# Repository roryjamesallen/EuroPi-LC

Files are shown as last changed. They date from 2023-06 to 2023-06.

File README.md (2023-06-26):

# EuroPi LC
### A Low-Cost Hardware Version of the [EuroPi](https://github.com/Allen-Synthesis/EuroPi)  



Hardware specifications:
- 4x Outputs (0-10V, smoothed PWM, each with indicator LED)
- 2x Inputs (Both capable of 0-10V analogue input, 12 bit, input 1 also capable of digital input with hardware interrupt)
- 2 Knobs (12 bit)
- 2 Push buttons
- 4HP wide (20.32mm)

### What actully *is* a "EuroPi LC"?
The EuroPi LC (Low-Cost) can be essentially seen as a '[HAT](https://www.raspberrypi.com/news/introducing-raspberry-pi-hats/)', but using a XIAO RP2040 instead of a full sized Raspberry Pi. Without going into too much depth, the circuit converts the 3.3V signals that the XIAO RP2040 deals with (both for inputs and outputs) into 0-10V signals which are more useful in a Eurorack context. The knobs and buttons are just extra components added for the user to work with in their code. If you plan on just using code other people have written, then ignore all the 'HAT' stuff, and just think of the EuroPi LC as any other Eurorack module.  
  
So what does "work with" actually mean? Well, the EuroPi LC (as with the standard hardware EuroPi, lots of this information is interchangeable) is a platform that can be used to bring your ideas for new modules to life using [MicroPython](https://micropython.org/). In the same way that a Raspberry Pi HAT with some LEDs on it allows your Raspberry Pi code to interact with some LEDs, the EuroPi LC allows your XIAO RP2040 code to interact with all the other modules in your Eurorack system.  
  
For example, you can write basic scripts using commands as simple as `cv3.voltage(2)` to set CV (Control Voltage) output 4 to 2 volts, which you can then plug into another module and voila - your MicroPython script is now directly controlling another module in your rack, and you have *complete* control over what it does. Of course it can get a lot *lot* more complex than setting a single CV output to a voltage, and eventually you end up with scripts like quantizers, polyrhythmic sequencers, and complex synced LFOs.

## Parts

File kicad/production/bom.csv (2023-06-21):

Designator | Footprint | Quantity | Value | LCSC Part #
C1, C2 | 0603 | 2 | 10u | C96446
C10, C11, C12, C13, C14, C3, C4, C5, C6, C7, C8, C9 | 0402 | 12 | 100n | C307331
D2, D3 | D_SOD-123 | 2 | D | C8598
J1 | power-header-10-pin-unlabelled | 1 | Conn_02x05_Odd_Even
J4, J5, J6, J7, J8, J9 | jack-thonkiconn-mono | 6 | Thonkiconn
LED1, LED2, LED3, LED4 | led-3mm | 4 | LED
P1, P2 | potentiometer-9mm | 2 | Potentiometer_9mm_Vertical_Linear
Q1 | SOT-23 | 1 | S8050
R1, R11, R12, R17, R18, R2, R27, R7, R8 | 0402 | 9 | 1K | C11702
R10, R19, R20, R9 | 0402 | 4 | 5K6 | C25908
R13, R14, R3, R4 | 0402 | 4 | 33K | C25779
R15, R16, R5, R6 | 0402 | 4 | 75K | C25798
R21, R22, R23, R24, R28 | 0402 | 5 | 100K | C25741
R25, R26, R29 | 0402 | 3 | 47K | C25792
SW1, SW2 | PB01-109TL low Profile Illuminated Button | 2 | SW_Push_LED
U1 | SOIC-14_3.9x8.7mm_P1.27mm | 1 | TL074
U2 | SOIC-8_3.9x4.9mm_P1.27mm | 1 | MCP6002-xSN
U3 | SOT-89-3 | 1 | ~ | C71136
U4 | MOUDLE14P-2.54-21X17.8MM | 1 | SEEEDUINO-XIAO
U5, U6, U7 | TSOT-23-6 | 3 | ADC121C027CIMK

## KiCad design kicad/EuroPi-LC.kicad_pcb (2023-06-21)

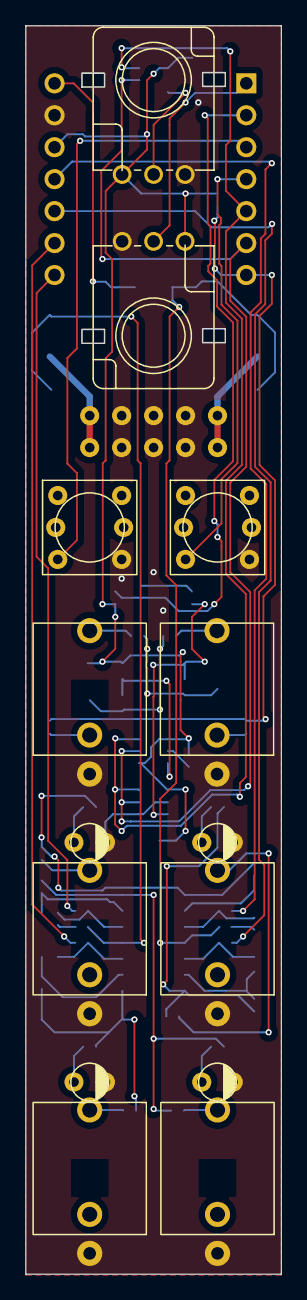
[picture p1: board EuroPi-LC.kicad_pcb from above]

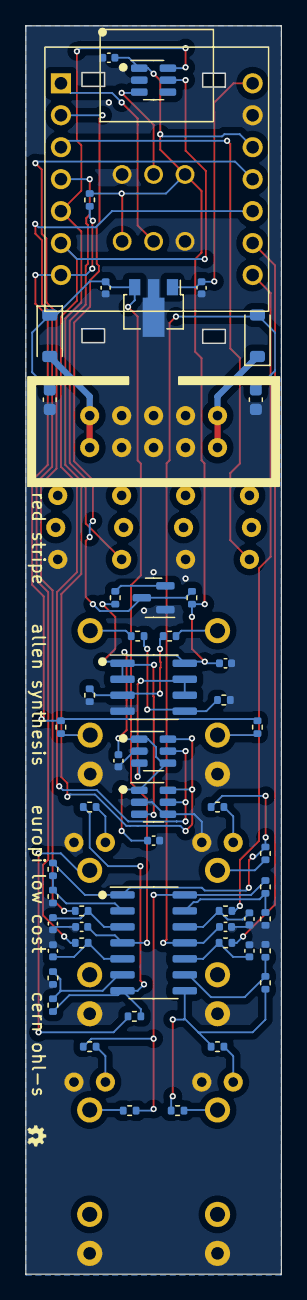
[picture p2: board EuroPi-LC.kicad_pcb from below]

Board: 2 copper layers, 20.3 x 99.2 mm, 68 parts (54 on the bottom side), 48 nets.

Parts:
C1, C2: 10u; C_0603_1608Metric
C3, C4, C5, C6, C7, C8, C9, C10, C11, C12, C13, C14: 100n; C_0402_1005Metric
D2, D3: D; D_SOD-123
J1: Conn_02x05_Odd_Even; power-header-10-pin-unlabelled
J4, J5, J6, J7, J8, J9: Thonkiconn; jack-thonkiconn-mono
LED1, LED2, LED3, LED4: LED; led-3mm
P1, P2: Potentiometer_9mm_Vertical_Linear; potentiometer-9mm
Q1: S8050; SOT-23
R1, R2, R7, R8, R11, R12, R17, R18, R27: 1K; R_0402_1005Metric
R3, R4, R13, R14: 33K; R_0402_1005Metric
R5, R6, R15, R16: 75K; R_0402_1005Metric
R9, R10, R19, R20: 5K6; R_0402_1005Metric
R21, R22, R23, R24, R28: 100K; R_0402_1005Metric
R25, R26, R29: 47K; R_0402_1005Metric
SW1, SW2: SW_Push_LED; PB01-109TL low Profile Illuminated Button
U1: TL074; SOIC-14_3.9x8.7mm_P1.27mm
U2: MCP6002-xSN; SOIC-8_3.9x4.9mm_P1.27mm
U3: SOT-89-3
U4: SEEEDUINO-XIAO; MOUDLE14P-2.54-21X17.8MM
U5, U6, U7: ADC121C027CIMK; TSOT-23-6

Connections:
+3V3: C9.1, C12.1, C13.1, C14.1, P1.1, P2.1, R27.1, R29.1, U2.8 (V+), U4.12 (3V3), U5.1 (V_{A}), U5.4 (ADDR), U6.1 (V_{A}), U7.1 (V_{A})
+5V: C11.1, U3.1 (OUT), U4.14 (5V)
+12V: C1.1, C5.1, C10.1, D2.1 (K), U1.4 (V+), U3.3 (IN)
-12V: C2.2, C6.2, D3.2 (A), U1.11 (V-)
ADC_SCL: U4.6 (PA9_A5_D5_SCL), U5.5 (SCL), U6.5 (SCL), U7.5 (SCL)
ADC_SDA: U4.5 (PA8_A4_D4_SDA), U5.6 (SDA), U6.6 (SDA), U7.6 (SDA)
BUTTON_1: SW1.2, U4.3 (PA10_A2_D2)
BUTTON_2: SW2.2, U4.4 (PA11_A3_D3)
DIGITAL_INPUT: Q1.3 (C), R29.2, U4.2 (PA4_A1_D1)
Earth: C1.2, C2.1, C3.2, C4.2, C5.2, C6.1, C7.2, C8.2, C9.2, C10.2, C11.2, C12.2, C13.2, C14.2, J1.3, J1.4, J1.5, J1.6, J1.7, J1.8, J4.1 (E), J5.1 (E), J6.1 (E), J7.1 (E), J8.1 (E), J9.1 (E), LED1.1 (K), LED2.1 (K), LED3.1 (K), LED4.1 (K), P1.3, P2.3, Q1.1 (E), R3.2, R4.2, R13.2, R14.2, R25.2, R26.2, SW1.4, SW2.4, U2.4 (V-), U3.2 (GND), U4.13 (GND), U5.2 (GND), U6.2 (GND), U6.4 (ADDR), U7.2 (GND)
INPUT_DETECT: R21.1, R23.1, R27.2, U4.7 (PB08_A6_D6_TX)
KNOB_1: P1.2, U7.3 (V_{IN})
KNOB_2: P2.2, U4.1 (PA02_A0_D0)
unnamed: D2.2 (A), J1.9, J1.10
unnamed: D3.1 (K), J1.1, J1.2
unnamed: J4.3 (T), R7.1
unnamed: J5.3 (T), R8.1
unnamed: J6.3 (T), R17.1
unnamed: J7.3 (T), R18.1
unnamed: J8.3 (T), R22.2
unnamed: J8.2 (TN), R21.2
unnamed: J9.3 (T), R24.2
unnamed: J9.2 (TN), R23.2
unnamed: LED1.2 (A), R9.1
unnamed: LED2.2 (A), R10.1
unnamed: LED3.2 (A), R19.1
unnamed: LED4.2 (A), R20.1
unnamed: Q1.2 (B), R28.1
unnamed: R5.2, R7.2, R9.2, U1.1
unnamed: R6.2, R8.2, R10.2, U1.8
unnamed: R15.2, R17.2, R19.2, U1.7
unnamed: R16.2, R18.2, R20.2, U1.14
unnamed: C3.1, R1.1, U1.3 (+)
unnamed: R3.1, R5.1, U1.2 (-)
unnamed: C7.1, R11.1, U1.5 (+)
unnamed: R13.1, R15.1, U1.6 (-)
unnamed: C4.1, R2.1, U1.10 (+)
unnamed: R4.1, R6.1, U1.9 (-)
unnamed: C8.1, R12.1, U1.12 (+)
unnamed: R14.1, R16.1, U1.13 (-)
unnamed: R22.1, R25.1, U2.3 (+)
unnamed: R28.2, U2.1, U2.2 (-), U6.3 (V_{IN})
unnamed: R24.1, R26.1, U2.5 (+)
unnamed: U2.6 (-), U2.7, U5.3 (V_{IN})
OUTPUT_1: R1.2, U4.11 (PA6_A10_D10_MOSI)
OUTPUT_2: R11.2, U4.10 (PA5_A9_D9_MISO)
OUTPUT_3: R2.2, U4.9 (PA7_A8_D8_SCK)
OUTPUT_4: R12.2, U4.8 (PB09_A7_D7_RX)

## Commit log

2023-06-07 make 4hp
    [EuroPi LC.kicad_pcb, EuroPi LC.kicad_sch, inputs.kicad_sch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]
2023-06-20 input changes
    use single channel ADCs for analog inputs and knob 1 which use i2c instead of SPI to free up one pin for input 1 to be used as a digital input as well
    [EuroPi LC.kicad_pcb, EuroPi LC.kicad_sch, controls.kicad_sch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]
2023-06-20 reroute pcb
    [EuroPi LC.kicad_pcb, EuroPi LC.kicad_sch, controls.kicad_sch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]
2023-06-20 pcb updates
    [EuroPi LC.kicad_pcb, bom.csv, designators.csv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]
2023-06-21 add schematic notes
    [EuroPi LC.kicad_sch, bom.csv, controls.kicad_sch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]
2023-06-28 add hyphen to filenames
    [EuroPi-LC.kicad_pcb, EuroPi-LC.kicad_sch]

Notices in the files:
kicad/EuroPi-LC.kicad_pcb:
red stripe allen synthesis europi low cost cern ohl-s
